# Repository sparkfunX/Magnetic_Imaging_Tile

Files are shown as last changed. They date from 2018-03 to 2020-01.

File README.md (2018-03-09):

Magnetic Imaging Tile
======

SparkFun Magnetic Imaging Tile

[*SparkFun Magnetic Imaging Tile (SPX-14652)*](https://www.sparkfun.com/products/14652)

The Magnetic Imaging Tile uses an array of 64 hall effect sensors to convert magnetic fields to the visual spectrum. That's right! You can now see magnetic fields in real time! As is to be expected, there are caveats: the magnetic sensors used on the tile are some of the most sensitive on the market but you need to be within 1 to 2 centimeters of the tile to get a good image.

This is a board intended to function as a "magnetic field camera" to visualize magnetic fields. 

This is an endorsed fork and collaboration of [Peter Jansen's work](https://hackaday.io/project/18518-iteration-8/log/91551-a-third-high-speed-magnetic-imager-tile). All credit goes to him! SparkX has re-designed the PCB for DFM and simiplified some of the platform interfacing code.

### Version 3.0

The major advancement of v3.0 is a dramatic increase in the speed with which the tile data can be read out. ~2000 frames per second (fps) can be achieved which allows visualizing even quickly varying fields (e.g. those in a 60Hz transformer, or a moving motor). Version 3.0 reduces the size of the tile to an 8x8 grid of hall effect sensors (64 total), arrayed in a 4mm grid.  The boards is tile-able with up to 4 of the boards tileable with minimal borders to create a 16x16 array. 

For more information (and a video of the v3.0 tile in use), please see: 
https://hackaday.io/project/18518-iteration-8/log/91551-a-third-high-speed-magnetic-imager-tile-draft

Repository Contents
-------------------

* **/Documents** - Datasheets for the RV-1805-C3 and super capacitor
* **/Hardware** - Eagle design files (.brd, .sch)

License Information
-------------------

This product is _**open source**_! 

Please review the LICENSE.md file for license information. 

If you have any questions or concerns on licensing, please contact techsupport@sparkfun.com.

Please use, reuse, and modify these files as you see fit. Please maintain attribution to SparkFun Electronics and release any derivative under the same license.

Disclaimer
-------------------

**DISCLAIMER OF WARRANTIES AND LIMITATION OF LIABILITY.**

UNLESS OTHERWISE SEPARATELY UNDERTAKEN BY THE LICENSOR, TO THE EXTENT POSSIBLE, THE LICENSOR OFFERS THE LICENSED MATERIAL AS-IS AND AS-AVAILABLE, AND MAKES NO REPRESENTATIONS OR WARRANTIES OF ANY KIND CONCERNING THE LICENSED MATERIAL, WHETHER EXPRESS, IMPLIED, STATUTORY, OR OTHER. THIS INCLUDES, WITHOUT LIMITATION, WARRANTIES OF TITLE, MERCHANTABILITY, FITNESS FOR A PARTICULAR PURPOSE, NON-INFRINGEMENT, ABSENCE OF LATENT OR OTHER DEFECTS, ACCURACY, OR THE PRESENCE OR ABSENCE OF ERRORS, WHETHER OR NOT KNOWN OR DISCOVERABLE. WHERE DISCLAIMERS OF WARRANTIES ARE NOT ALLOWED IN FULL OR IN PART, THIS DISCLAIMER MAY NOT APPLY TO YOU.

TO THE EXTENT POSSIBLE, IN NO EVENT WILL THE LICENSOR BE LIABLE TO YOU ON ANY LEGAL THEORY (INCLUDING, WITHOUT LIMITATION, NEGLIGENCE) OR OTHERWISE FOR ANY DIRECT, SPECIAL, INDIRECT, INCIDENTAL, CONSEQUENTIAL, PUNITIVE, EXEMPLARY, OR OTHER LOSSES, COSTS, EXPENSES, OR DAMAGES ARISING OUT OF THIS PUBLIC LICENSE OR USE OF THE LICENSED MATERIAL, EVEN IF THE LICENSOR HAS BEEN ADVISED OF THE POSSIBILITY OF SUCH LOSSES, COSTS, EXPENSES, OR DAMAGES. WHERE A LIMITATION OF LIABILITY IS NOT ALLOWED IN FULL OR IN PART, THIS LIMITATION MAY NOT APPLY TO YOU.

THE DISCLAIMER OF WARRANTIES AND LIMITATION OF LIABILITY PROVIDED ABOVE SHALL BE INTERPRETED IN A MANNER THAT, TO THE EXTENT POSSIBLE, MOST CLOSELY APPROXIMATES AN ABSOLUTE DISCLAIMER AND WAIVER OF ALL LIABILITY.

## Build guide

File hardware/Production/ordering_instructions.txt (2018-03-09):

panel size, 105x104mm
PCB thickness, 1.6mm
number of layers, 2
soldermask color, Black
silkscreen color, white
oz copper, 1oz
finish, HASL lead free
stencils, top+bottom

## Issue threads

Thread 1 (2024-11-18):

SCK and CLK labels are wrong on the mux side of the board

TurnerRussell50, 2024-11-18:
The hall-effect side is labeled correctly

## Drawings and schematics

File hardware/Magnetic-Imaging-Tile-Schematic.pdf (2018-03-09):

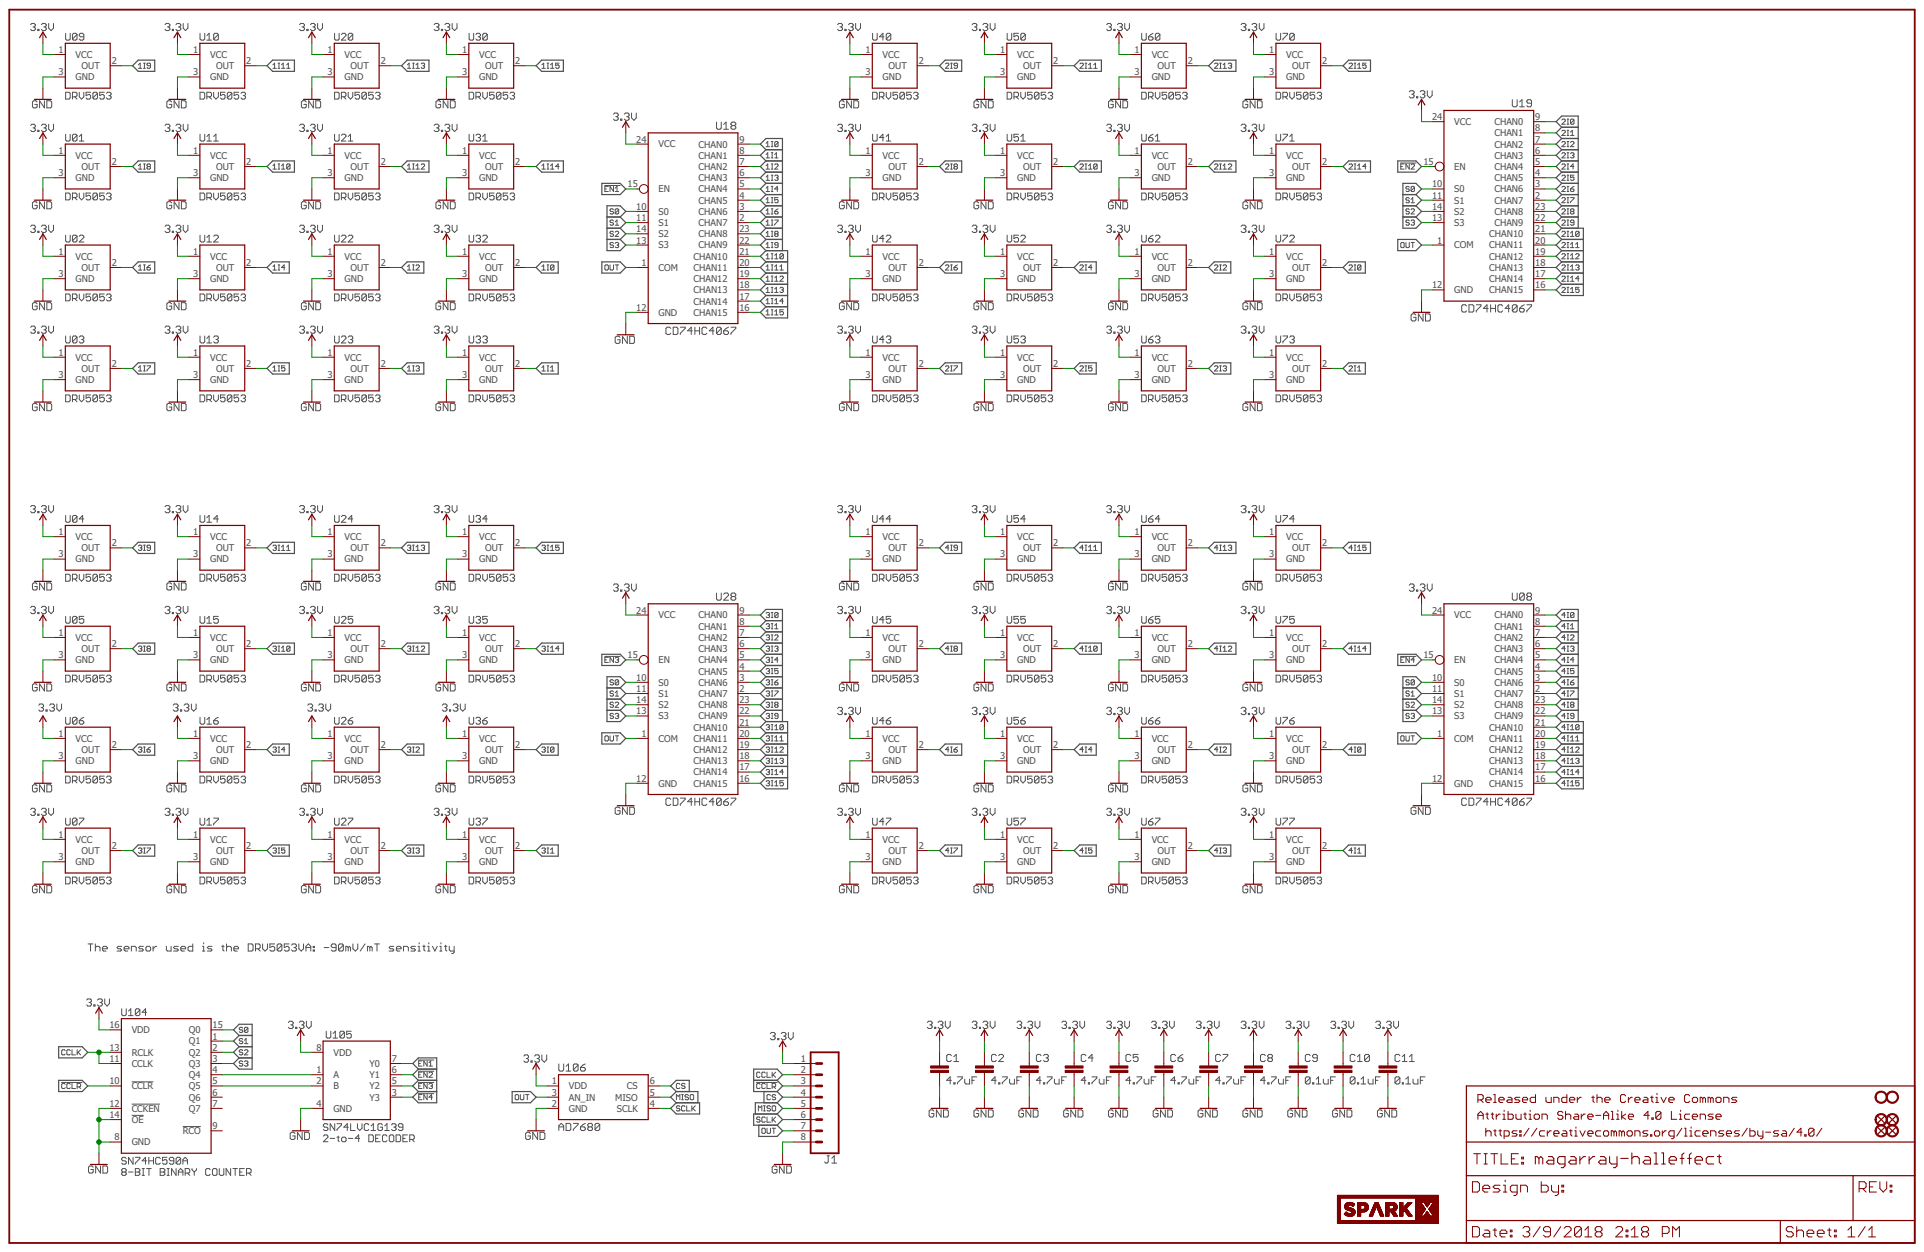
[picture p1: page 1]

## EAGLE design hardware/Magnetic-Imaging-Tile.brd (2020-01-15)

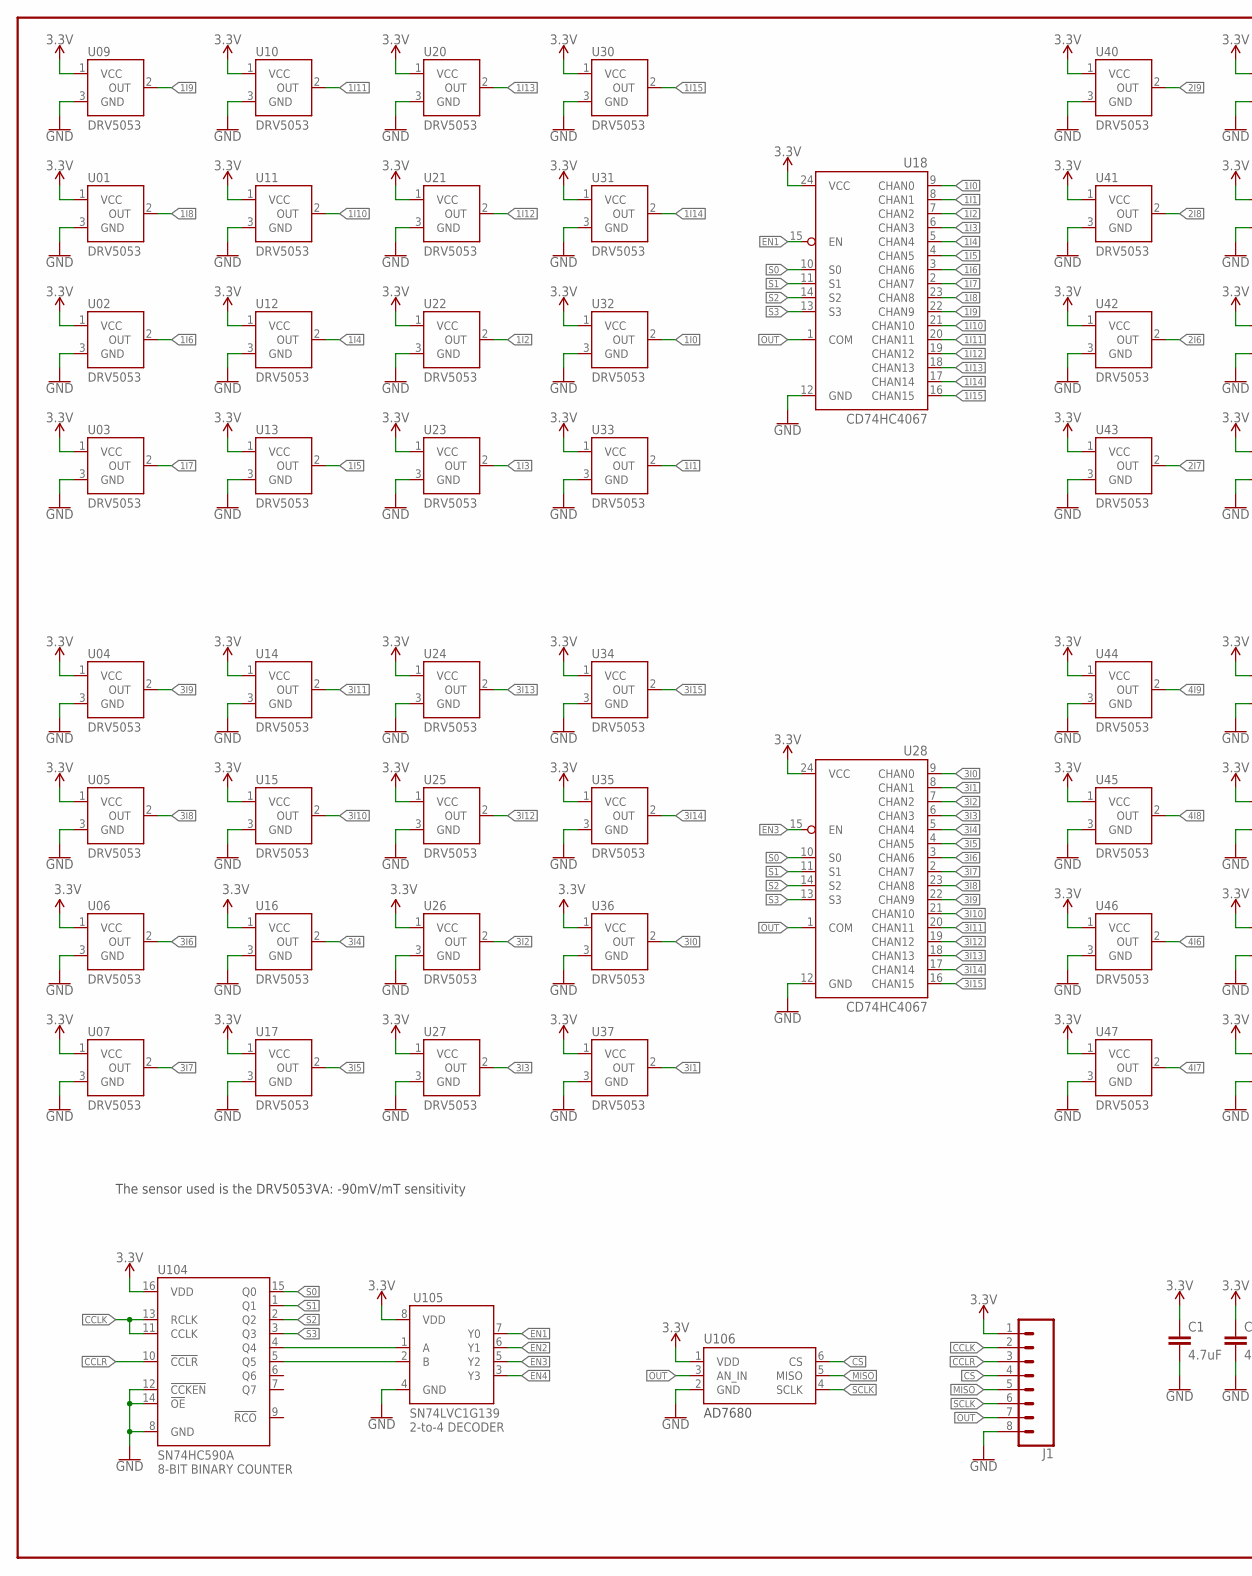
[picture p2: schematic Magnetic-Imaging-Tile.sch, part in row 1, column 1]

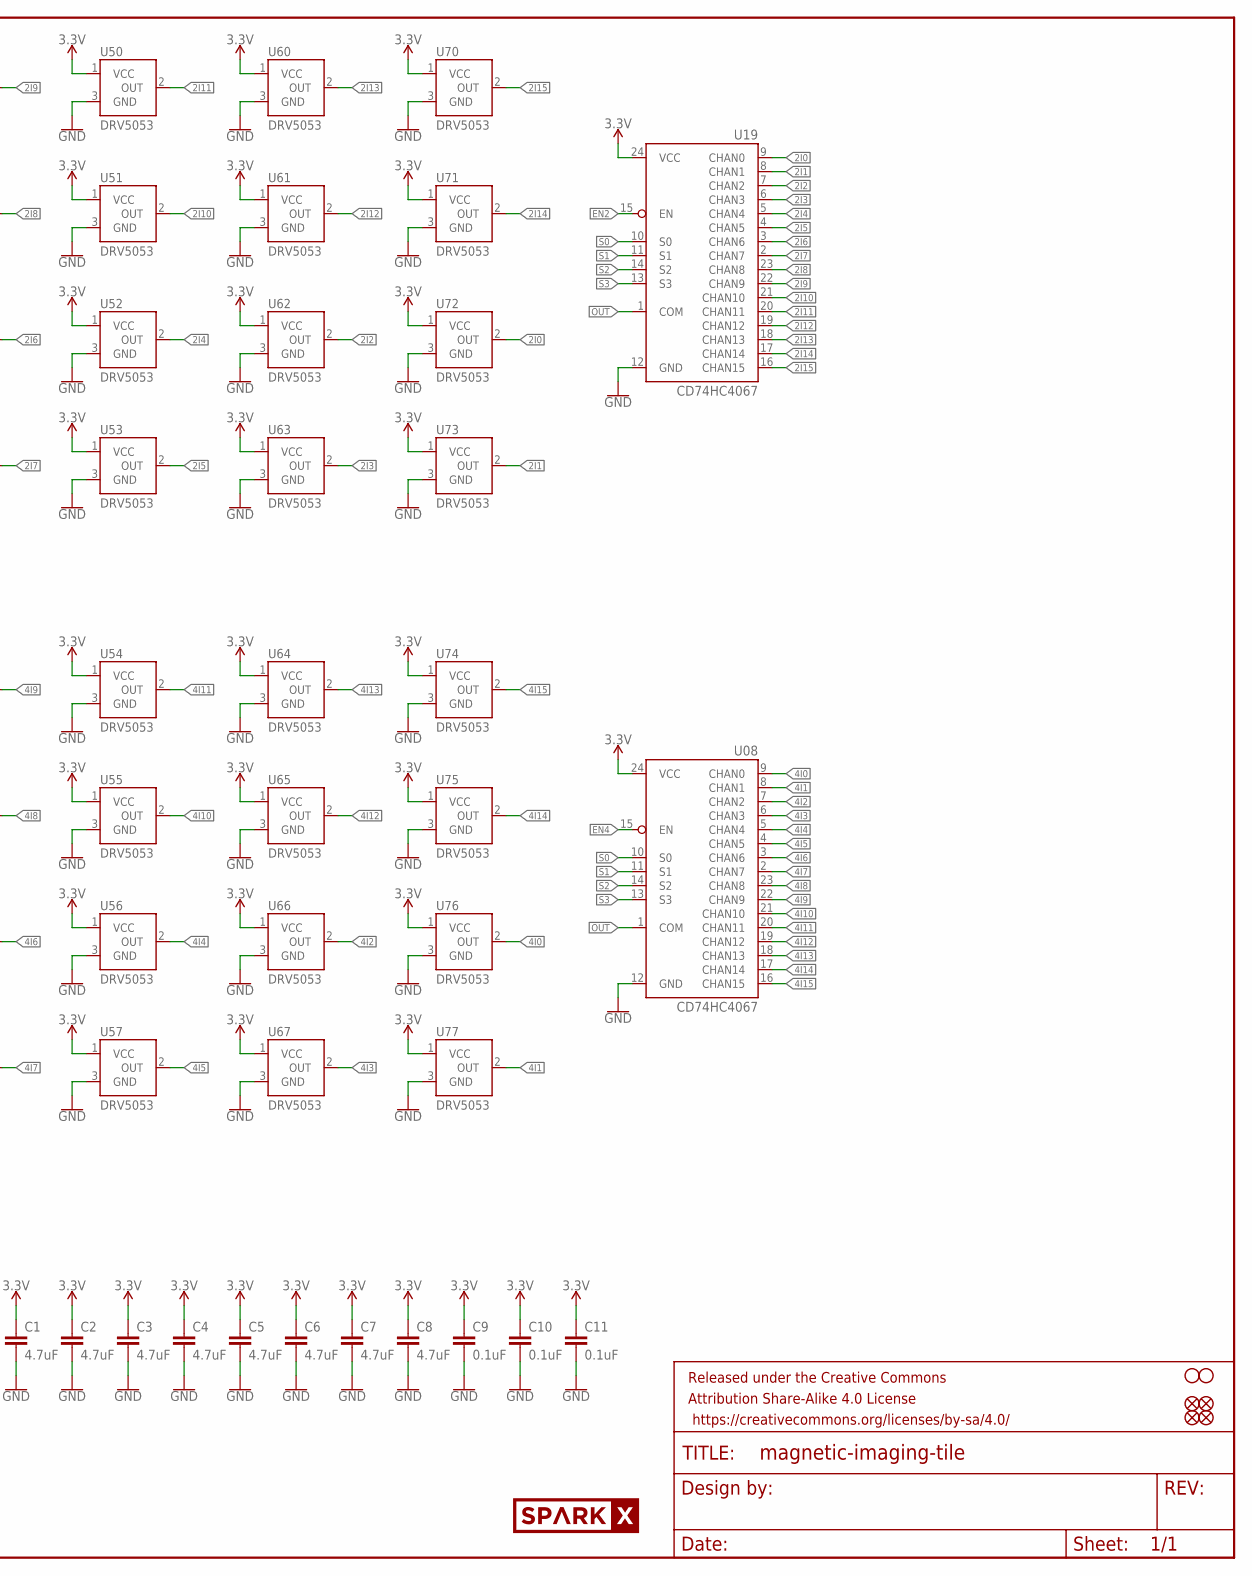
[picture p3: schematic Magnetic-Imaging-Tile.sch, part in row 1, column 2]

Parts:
C1, C2, C3, C4, C5, C6, C7, C8: 4.7uF; 0603
C9, C10, C11: 0.1uF; 0603
FD1, FD2, FD3, FD4: FIDUCIALUFIDUCIAL; FIDUCIAL-MICRO
FRAME1: FRAME-LEDGER; CREATIVE_COMMONS
H1, H2: STAND-OFF
J1: CONN_08LOCK_NO_SILK; 1X08_LOCK_NO_SILK
U01, U02, U03, U04, U05, U06, U07, U09, U10, U11, U12, U13, U14, U15, U16, U17, U20, U21, U22, U23, U24, U25, U26, U27, U30, U31, U32, U33, U34, U35, U36, U37, U40, U41, U42, U43, U44, U45, U46, U47, U50, U51, U52, U53, U54, U55, U56, U57, U60, U61, U62, U63, U64, U65, U66, U67, U70, U71, U72, U73, U74, U75, U76, U77: DRV5053; SOT23-3
U08, U18, U19, U28: CD74HC4067; SSOP24
U104: SN74HC590A; SO16
U105: SN74LVC1G139; SM8
U106: AD7680; SOT23-6
U$1: SPARKX-LOGO3; SPARKX-SMALL

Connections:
1I0: U18.9 (CHAN0), U32.2 (OUT)
1I1: U18.8 (CHAN1), U33.2 (OUT)
1I2: U18.7 (CHAN2), U22.2 (OUT)
1I3: U18.6 (CHAN3), U23.2 (OUT)
1I4: U12.2 (OUT), U18.5 (CHAN4)
1I5: U13.2 (OUT), U18.4 (CHAN5)
1I6: U02.2 (OUT), U18.3 (CHAN6)
1I7: U03.2 (OUT), U18.2 (CHAN7)
1I8: U01.2 (OUT), U18.23 (CHAN8)
1I9: U09.2 (OUT), U18.22 (CHAN9)
1I10: U11.2 (OUT), U18.21 (CHAN10)
1I11: U10.2 (OUT), U18.20 (CHAN11)
1I12: U18.19 (CHAN12), U21.2 (OUT)
1I13: U18.18 (CHAN13), U20.2 (OUT)
1I14: U18.17 (CHAN14), U31.2 (OUT)
1I15: U18.16 (CHAN15), U30.2 (OUT)
2I0: U19.9 (CHAN0), U72.2 (OUT)
2I1: U19.8 (CHAN1), U73.2 (OUT)
2I2: U19.7 (CHAN2), U62.2 (OUT)
2I3: U19.6 (CHAN3), U63.2 (OUT)
2I4: U19.5 (CHAN4), U52.2 (OUT)
2I5: U19.4 (CHAN5), U53.2 (OUT)
2I6: U19.3 (CHAN6), U42.2 (OUT)
2I7: U19.2 (CHAN7), U43.2 (OUT)
2I8: U19.23 (CHAN8), U41.2 (OUT)
2I9: U19.22 (CHAN9), U40.2 (OUT)
2I10: U19.21 (CHAN10), U51.2 (OUT)
2I11: U19.20 (CHAN11), U50.2 (OUT)
2I12: U19.19 (CHAN12), U61.2 (OUT)
2I13: U19.18 (CHAN13), U60.2 (OUT)
2I14: U19.17 (CHAN14), U71.2 (OUT)
2I15: U19.16 (CHAN15), U70.2 (OUT)
3.3V: C1.1, C2.1, C3.1, C4.1, C5.1, C6.1, C7.1, C8.1, C9.1, C10.1, C11.1, J1.1, U01.1 (VCC), U02.1 (VCC), U03.1 (VCC), U04.1 (VCC), U05.1 (VCC), U06.1 (VCC), U07.1 (VCC), U08.24 (VCC), U09.1 (VCC), U10.1 (VCC), U11.1 (VCC), U12.1 (VCC), U13.1 (VCC), U14.1 (VCC), U15.1 (VCC), U16.1 (VCC), U17.1 (VCC), U18.24 (VCC), U19.24 (VCC), U20.1 (VCC), U21.1 (VCC), U22.1 (VCC), U23.1 (VCC), U24.1 (VCC), U25.1 (VCC), U26.1 (VCC), U27.1 (VCC), U28.24 (VCC), U30.1 (VCC), U31.1 (VCC), U32.1 (VCC), U33.1 (VCC), U34.1 (VCC), U35.1 (VCC), U36.1 (VCC), U37.1 (VCC), U40.1 (VCC), U41.1 (VCC), U42.1 (VCC), U43.1 (VCC), U44.1 (VCC), U45.1 (VCC), U46.1 (VCC), U47.1 (VCC), U50.1 (VCC), U51.1 (VCC), U52.1 (VCC), U53.1 (VCC), U54.1 (VCC), U55.1 (VCC), U56.1 (VCC), U57.1 (VCC), U60.1 (VCC), U61.1 (VCC), U62.1 (VCC), U63.1 (VCC), U64.1 (VCC), U65.1 (VCC), U66.1 (VCC), U67.1 (VCC), U70.1 (VCC), U71.1 (VCC), U72.1 (VCC), U73.1 (VCC), U74.1 (VCC), U75.1 (VCC), U76.1 (VCC), U77.1 (VCC), U104.16 (VDD), U105.8 (VDD), U106.1 (VDD)
3I0: U28.9 (CHAN0), U36.2 (OUT)
3I1: U28.8 (CHAN1), U37.2 (OUT)
3I2: U26.2 (OUT), U28.7 (CHAN2)
3I3: U27.2 (OUT), U28.6 (CHAN3)
3I4: U16.2 (OUT), U28.5 (CHAN4)
3I5: U17.2 (OUT), U28.4 (CHAN5)
3I6: U06.2 (OUT), U28.3 (CHAN6)
3I7: U07.2 (OUT), U28.2 (CHAN7)
3I8: U05.2 (OUT), U28.23 (CHAN8)
3I9: U04.2 (OUT), U28.22 (CHAN9)
3I10: U15.2 (OUT), U28.21 (CHAN10)
3I11: U14.2 (OUT), U28.20 (CHAN11)
3I12: U25.2 (OUT), U28.19 (CHAN12)
3I13: U24.2 (OUT), U28.18 (CHAN13)
3I14: U28.17 (CHAN14), U35.2 (OUT)
3I15: U28.16 (CHAN15), U34.2 (OUT)
4I0: U08.9 (CHAN0), U76.2 (OUT)
4I1: U08.8 (CHAN1), U77.2 (OUT)
4I2: U08.7 (CHAN2), U66.2 (OUT)
4I3: U08.6 (CHAN3), U67.2 (OUT)
4I4: U08.5 (CHAN4), U56.2 (OUT)
4I5: U08.4 (CHAN5), U57.2 (OUT)
4I6: U08.3 (CHAN6), U46.2 (OUT)
4I7: U08.2 (CHAN7), U47.2 (OUT)
4I8: U08.23 (CHAN8), U45.2 (OUT)
4I9: U08.22 (CHAN9), U44.2 (OUT)
4I10: U08.21 (CHAN10), U55.2 (OUT)
4I11: U08.20 (CHAN11), U54.2 (OUT)
4I12: U08.19 (CHAN12), U65.2 (OUT)
4I13: U08.18 (CHAN13), U64.2 (OUT)
4I14: U08.17 (CHAN14), U75.2 (OUT)
4I15: U08.16 (CHAN15), U74.2 (OUT)
!CCLR: J1.3, U104.10 (!CCLR)
!EN1: U18.15 (EN), U105.7 (Y0)
!EN2: U19.15 (EN), U105.6 (Y1)
!EN3: U28.15 (EN), U105.5 (Y2)
!EN4: U08.15 (EN), U105.3 (Y3)
CCLK: J1.2, U104.11 (CCLK), U104.13 (RCLK)
CS: J1.4, U106.6 (CS)
GND: C1.2, C2.2, C3.2, C4.2, C5.2, C6.2, C7.2, C8.2, C9.2, C10.2, C11.2, J1.8, U01.3 (GND), U02.3 (GND), U03.3 (GND), U04.3 (GND), U05.3 (GND), U06.3 (GND), U07.3 (GND), U08.12 (GND), U09.3 (GND), U10.3 (GND), U11.3 (GND), U12.3 (GND), U13.3 (GND), U14.3 (GND), U15.3 (GND), U16.3 (GND), U17.3 (GND), U18.12 (GND), U19.12 (GND), U20.3 (GND), U21.3 (GND), U22.3 (GND), U23.3 (GND), U24.3 (GND), U25.3 (GND), U26.3 (GND), U27.3 (GND), U28.12 (GND), U30.3 (GND), U31.3 (GND), U32.3 (GND), U33.3 (GND), U34.3 (GND), U35.3 (GND), U36.3 (GND), U37.3 (GND), U40.3 (GND), U41.3 (GND), U42.3 (GND), U43.3 (GND), U44.3 (GND), U45.3 (GND), U46.3 (GND), U47.3 (GND), U50.3 (GND), U51.3 (GND), U52.3 (GND), U53.3 (GND), U54.3 (GND), U55.3 (GND), U56.3 (GND), U57.3 (GND), U60.3 (GND), U61.3 (GND), U62.3 (GND), U63.3 (GND), U64.3 (GND), U65.3 (GND), U66.3 (GND), U67.3 (GND), U70.3 (GND), U71.3 (GND), U72.3 (GND), U73.3 (GND), U74.3 (GND), U75.3 (GND), U76.3 (GND), U77.3 (GND), U104.8 (GND), U104.12 (!CCKEN), U104.14 (!OE), U105.4 (GND), U106.2 (GND)
MISO: J1.5, U106.5 (MISO)
unnamed: U104.4 (Q4), U105.1 (A)
unnamed: U104.5 (Q5), U105.2 (B)
OUT: J1.7, U08.1 (COM), U18.1 (COM), U19.1 (COM), U28.1 (COM), U106.3 (AN_IN)
S0: U08.10 (S0), U18.10 (S0), U19.10 (S0), U28.10 (S0), U104.15 (Q0)
S1: U08.11 (S1), U18.11 (S1), U19.11 (S1), U28.11 (S1), U104.1 (Q1)
S2: U08.14 (S2), U18.14 (S2), U19.14 (S2), U28.14 (S2), U104.2 (Q2)
S3: U08.13 (S3), U18.13 (S3), U19.13 (S3), U28.13 (S3), U104.3 (Q3)
SCLK: J1.6, U106.4 (SCLK)

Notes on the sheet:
The sensor used is the DRV5053VA: -90mV/mT sensitivity

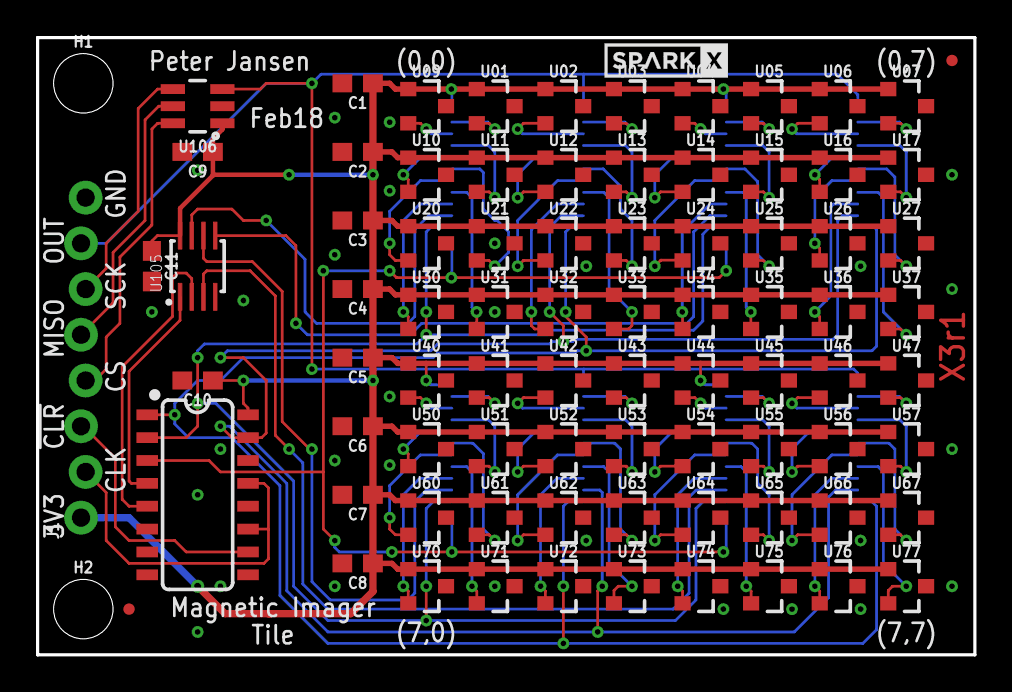
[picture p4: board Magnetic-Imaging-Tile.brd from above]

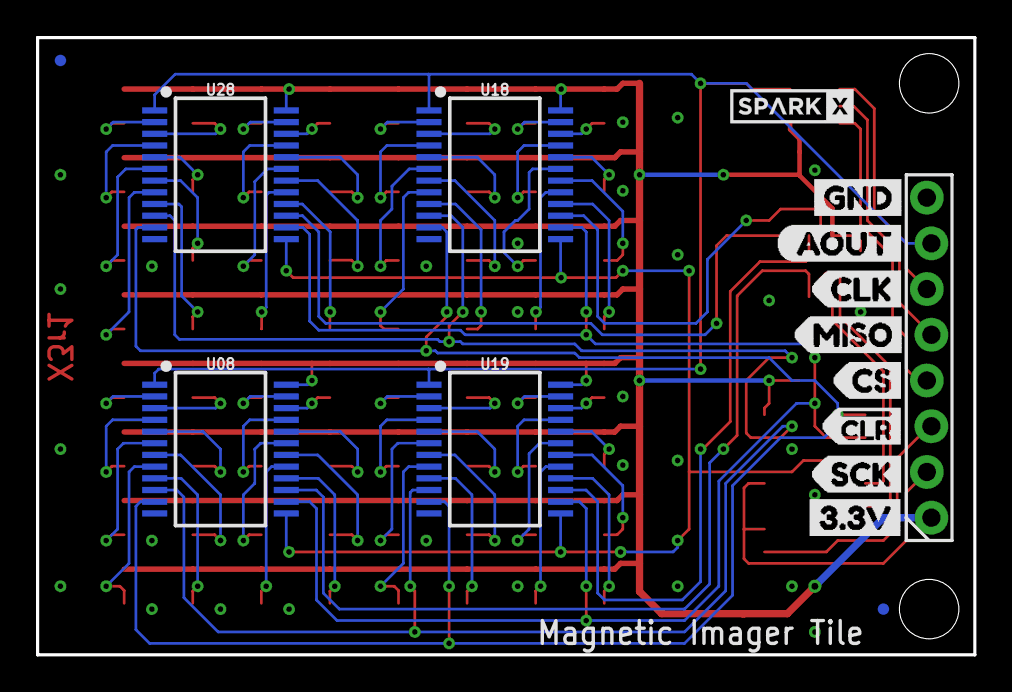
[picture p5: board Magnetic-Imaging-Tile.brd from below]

Board: 2 copper layers, 52.1 x 34.3 mm, 100 parts (15 on the bottom side), 82 nets.

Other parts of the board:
U$2: SPARKX-LOGO3; SPARKX-SMALL
U$3: GND
U$4: #CLR
U$5: 3#3V
U$6: AOUT
U$7: CLK
U$8: MISO
U$9: SCK
U$10: CS

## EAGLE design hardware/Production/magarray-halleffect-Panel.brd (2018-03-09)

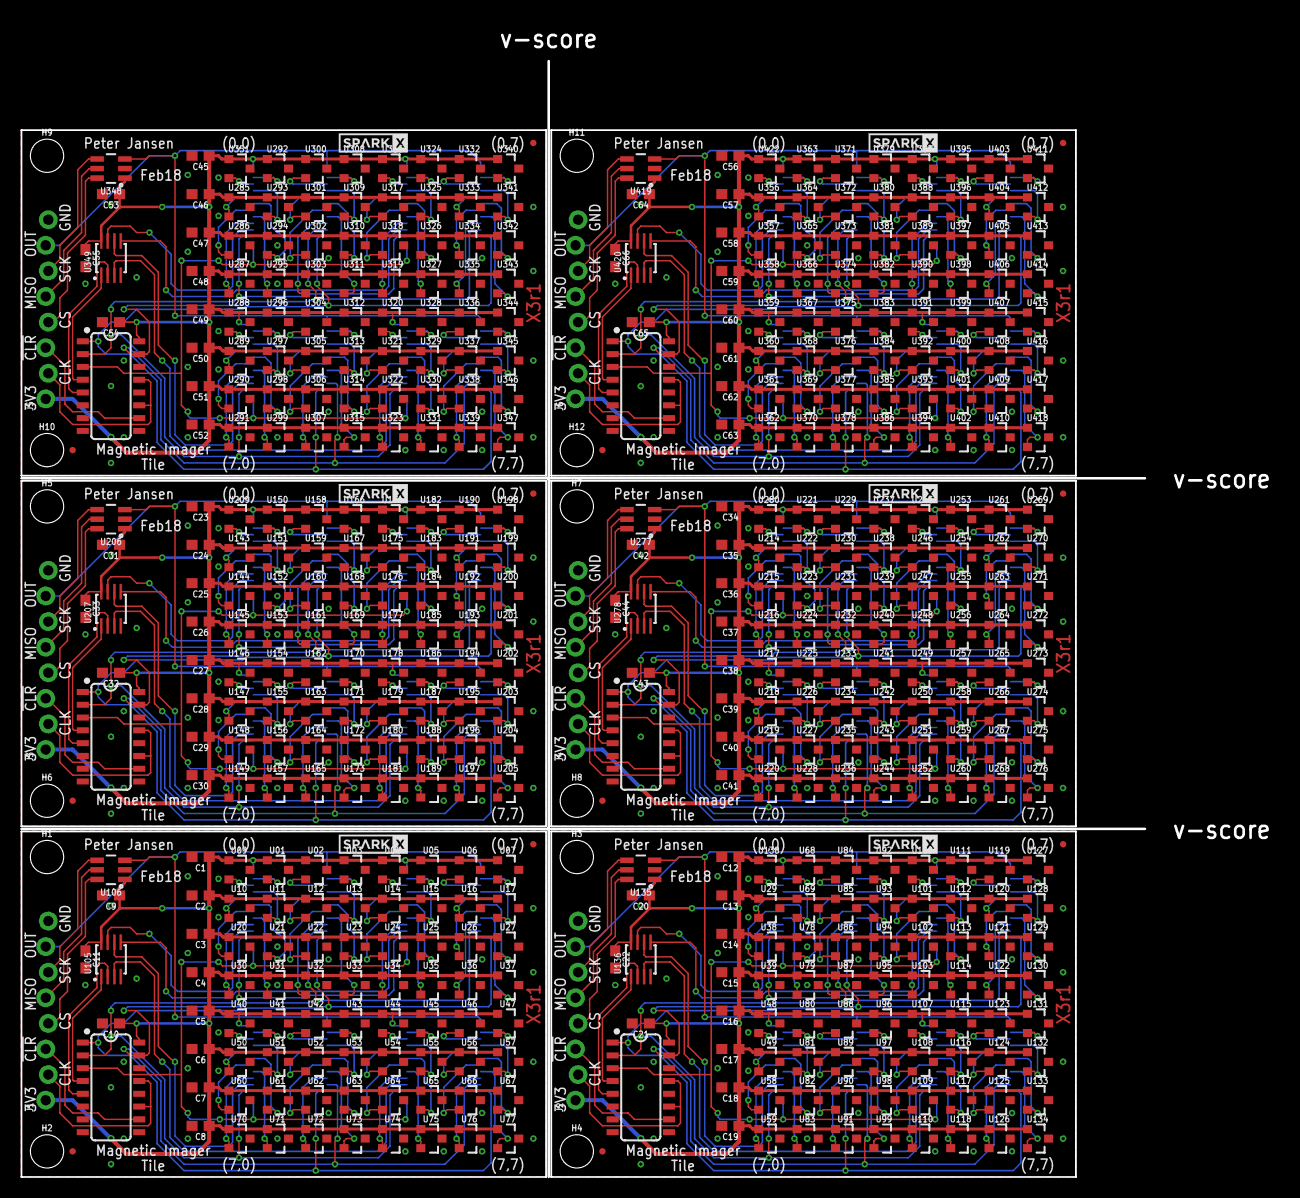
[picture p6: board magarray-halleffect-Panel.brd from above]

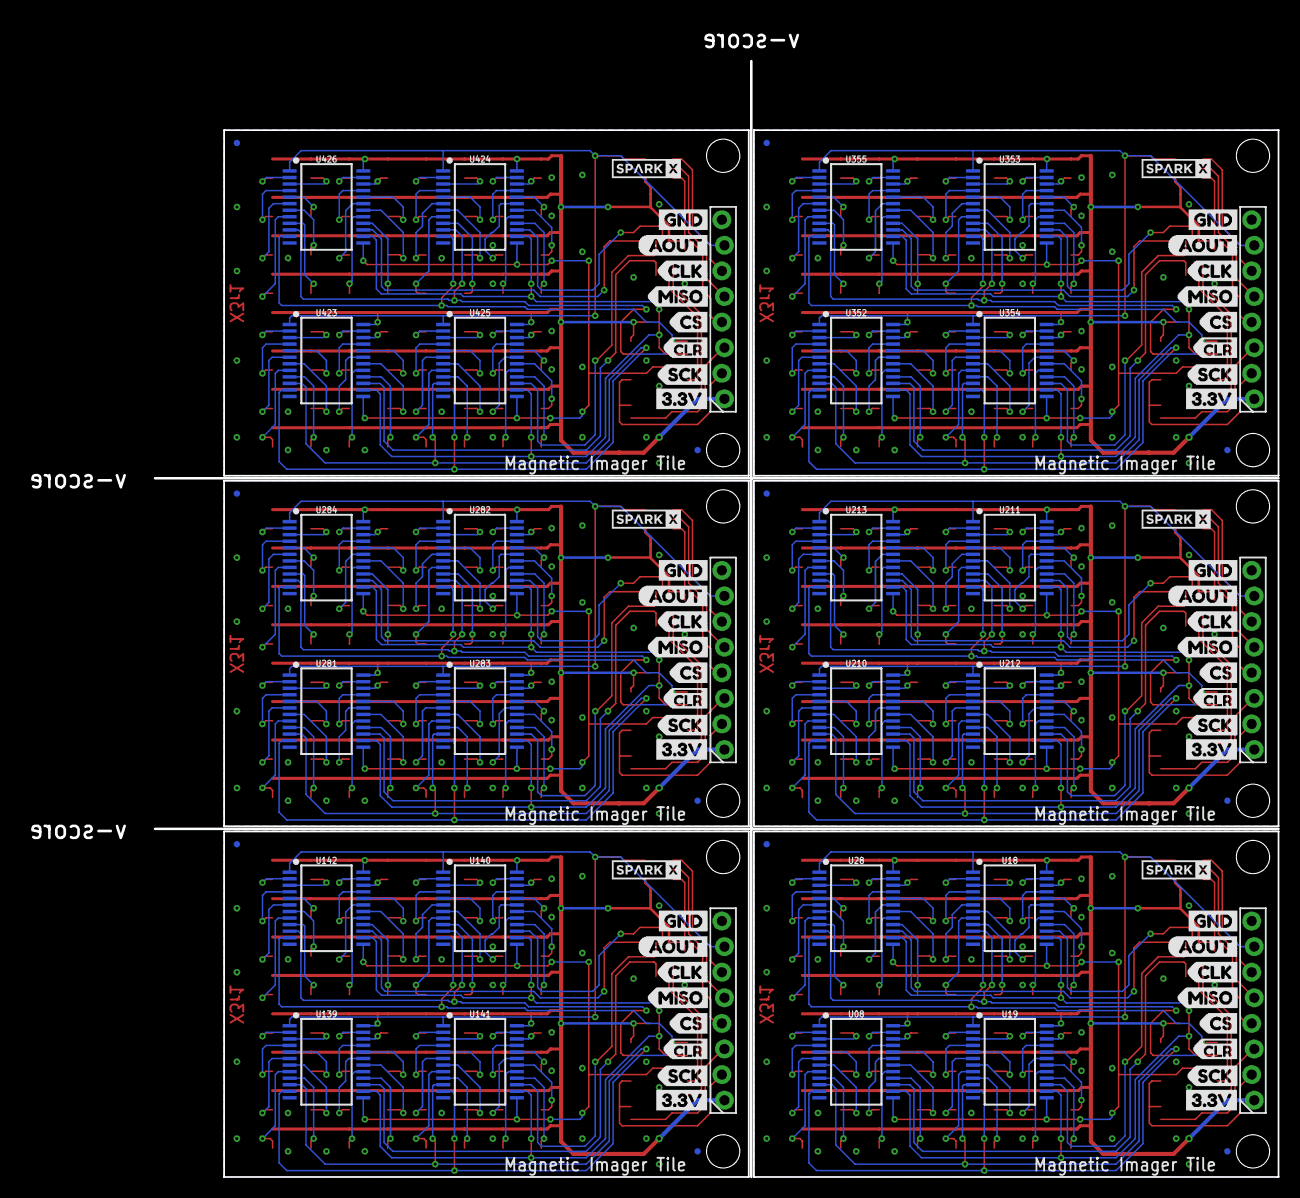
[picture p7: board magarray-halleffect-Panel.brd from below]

Board: 2 copper layers, 111.5 x 110.7 mm, 594 parts (90 on the bottom side), 492 nets.

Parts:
C1, C2, C3, C4, C5, C6, C7, C8, C12, C13, C14, C15, C16, C17, C18, C19, C23, C24, C25, C26, C27, C28, C29, C30, C34, C35, C36, C37, C38, C39, C40, C41, C45, C46, C47, C48, C49, C50, C51, C52, C56, C57, C58, C59, C60, C61, C62, C63: 4.7uF; 0603
C9, C10, C11, C20, C21, C22, C31, C32, C33, C42, C43, C44, C53, C54, C55, C64, C65, C66: 0.1uF; 0603
FD1, FD2, FD3, FD4, FD5, FD6, FD7, FD8, FD9, FD10, FD11, FD12, FD13, FD14, FD15, FD16, FD17, FD18, FD19, FD20, FD21, FD22, FD23, FD24: FIDUCIALUFIDUCIAL; FIDUCIAL-MICRO
H1, H2, H3, H4, H5, H6, H7, H8, H9, H10, H11, H12: STAND-OFF
J1, J2, J3, J4, J5, J6: 1X08_LOCK_NO_SILK
U01, U02, U03, U04, U05, U06, U07, U09, U10, U11, U12, U13, U14, U15, U16, U17, U20, U21, U22, U23, U24, U25, U26, U27, U29, U30, U31, U32, U33, U34, U35, U36, U37, U38, U39, U40, U41, U42, U43, U44, U45, U46, U47, U48, U49, U50, U51, U52, U53, U54, U55, U56, U57, U58, U59, U60, U61, U62, U63, U64, U65, U66, U67, U68, U69, U70, U71, U72, U73, U74, U75, U76, U77, U78, U79, U80, U81, U82, U83, U84, U85, U86, U87, U88, U89, U90, U91, U92, U93, U94, U95, U96, U97, U98, U99, U100, U101, U102, U103, U107, U108, U109, U110, U111, U112, U113, U114, U115, U116, U117, U118, U119, U120, U121, U122, U123, U124, U125, U126, U127, U128, U129, U130, U131, U132, U133, U134, U138, U143, U144, U145, U146, U147, U148, U149, U150, U151, U152, U153, U154, U155, U156, U157, U158, U159, U160, U161, U162, U163, U164, U165, U166, U167, U168, U169, U170, U171, U172, U173, U174, U175, U176, U177, U178, U179, U180, U181, U182, U183, U184, U185, U186, U187, U188, U189, U190, U191, U192, U193, U194, U195, U196, U197, U198, U199, U200, U201, U202, U203, U204, U205, U209, U214, U215, U216, U217, U218, U219, U220, U221, U222, U223, U224, U225, U226, U227, U228, U229, U230, U231, U232, U233, U234, U235, U236, U237, U238, U239, U240, U241, U242, U243, U244, U245, U246, U247, U248, U249, U250, U251, U252, U253, U254, U255, U256, U257, U258, U259, U260, U261, U262, U263, U264, U265, U266, U267, U268, U269, U270, U271, U272, U273, U274, U275, U276, U280, U285, U286, U287, U288, U289, U290, U291, U292, U293, U294, U295, U296, U297, U298, U299, U300, U301, U302, U303, U304, U305, U306, U307, U308, U309, U310, U311, U312, U313, U314, U315, U316, U317, U318, U319, U320, U321, U322, U323, U324, U325, U326, U327, U328, U329, U330, U331, U332, U333, U334, U335, U336, U337, U338, U339, U340, U341, U342, U343, U344, U345, U346, U347, U351, U356, U357, U358, U359, U360, U361, U362, U363, U364, U365, U366, U367, U368, U369, U370, U371, U372, U373, U374, U375, U376, U377, U378, U379, U380, U381, U382, U383, U384, U385, U386, U387, U388, U389, U390, U391, U392, U393, U394, U395, U396, U397, U398, U399, U400, U401, U402, U403, U404, U405, U406, U407, U408, U409, U410, U411, U412, U413, U414, U415, U416, U417, U418, U422: DRV5053; SOT23-3
U08, U18, U19, U28, U139, U140, U141, U142, U210, U211, U212, U213, U281, U282, U283, U284, U352, U353, U354, U355, U423, U424, U425, U426: CD74HC4067; SSOP24
U104, U137, U208, U279, U350, U421: SN74HC509A; SO16
U105, U136, U207, U278, U349, U420: SN74LVC1G139; SM8
U106, U135, U206, U277, U348, U419: AD7940; SOT23-6
U$1, U$2, U$11, U$12, U$21, U$22, U$31, U$32, U$41, U$42, U$51, U$52: SPARKX-LOGO3; SPARKX-SMALL
U$3, U$13, U$23, U$33, U$43, U$53: GND
U$4, U$19, U$29, U$39, U$49, U$59: #CLR
U$5, U$14, U$24, U$34, U$44, U$54: 3#3V
U$6, U$15, U$25, U$35, U$45, U$55: AOUT
U$7, U$16, U$26, U$36, U$46, U$56: CLK
U$8, U$17, U$27, U$37, U$47, U$57: MISO
U$9, U$18, U$28, U$38, U$48, U$58: SCK
U$10, U$20, U$30, U$40, U$50, U$60: CS

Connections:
1I0: U18.9, U32.2
1I1: U18.8, U33.2
1I2: U18.7, U22.2
1I3: U18.6, U23.2
1I4: U12.2, U18.5
1I5: U13.2, U18.4
1I6: U02.2, U18.3
1I7: U03.2, U18.2
1I8: U01.2, U18.23
1I9: U09.2, U18.22
1I10: U11.2, U18.21
1I11: U10.2, U18.20
1I12: U18.19, U21.2
1I13: U18.18, U20.2
1I14: U18.17, U31.2
1I15: U18.16, U30.2
1I16: U87.2, U140.9
1I17: U95.2, U140.8
1I18: U86.2, U140.7
1I19: U94.2, U140.6
1I20: U85.2, U140.5
1I21: U93.2, U140.4
1I22: U84.2, U140.3
1I23: U92.2, U140.2
1I24: U68.2, U140.23
1I25: U138.2, U140.22
1I26: U69.2, U140.21
1I27: U29.2, U140.20
1I28: U78.2, U140.19
1I29: U38.2, U140.18
1I30: U79.2, U140.17
1I31: U39.2, U140.16
1I32: U161.2, U211.9
1I33: U169.2, U211.8
1I34: U160.2, U211.7
1I35: U168.2, U211.6
1I36: U159.2, U211.5
1I37: U167.2, U211.4
1I38: U158.2, U211.3
1I39: U166.2, U211.2
1I40: U150.2, U211.23
1I41: U209.2, U211.22
1I42: U151.2, U211.21
1I43: U143.2, U211.20
1I44: U152.2, U211.19
1I45: U144.2, U211.18
1I46: U153.2, U211.17
1I47: U145.2, U211.16
1I48: U232.2, U282.9
1I49: U240.2, U282.8
1I50: U231.2, U282.7
1I51: U239.2, U282.6
1I52: U230.2, U282.5
1I53: U238.2, U282.4
1I54: U229.2, U282.3
1I55: U237.2, U282.2
1I56: U221.2, U282.23
1I57: U280.2, U282.22
1I58: U222.2, U282.21
1I59: U214.2, U282.20
1I60: U223.2, U282.19
1I61: U215.2, U282.18
1I62: U224.2, U282.17
1I63: U216.2, U282.16
1I64: U303.2, U353.9
1I65: U311.2, U353.8
1I66: U302.2, U353.7
1I67: U310.2, U353.6
1I68: U301.2, U353.5
1I69: U309.2, U353.4
1I70: U300.2, U353.3
1I71: U308.2, U353.2
1I72: U292.2, U353.23
1I73: U351.2, U353.22
1I74: U293.2, U353.21
1I75: U285.2, U353.20
1I76: U294.2, U353.19
1I77: U286.2, U353.18
1I78: U295.2, U353.17
1I79: U287.2, U353.16
1I80: U374.2, U424.9
1I81: U382.2, U424.8
1I82: U373.2, U424.7
1I83: U381.2, U424.6
1I84: U372.2, U424.5
1I85: U380.2, U424.4
1I86: U371.2, U424.3
1I87: U379.2, U424.2
1I88: U363.2, U424.23
1I89: U422.2, U424.22
1I90: U364.2, U424.21
1I91: U356.2, U424.20
1I92: U365.2, U424.19
1I93: U357.2, U424.18
1I94: U366.2, U424.17
1I95: U358.2, U424.16
2I0: U19.9, U72.2
2I1: U19.8, U73.2
2I2: U19.7, U62.2
2I3: U19.6, U63.2
2I4: U19.5, U52.2
2I5: U19.4, U53.2
2I6: U19.3, U42.2
2I7: U19.2, U43.2
2I8: U19.23, U41.2
2I9: U19.22, U40.2
2I10: U19.21, U51.2
2I11: U19.20, U50.2
2I12: U19.19, U61.2
2I13: U19.18, U60.2
2I14: U19.17, U71.2
2I15: U19.16, U70.2
2I16: U91.2, U141.9
2I17: U99.2, U141.8
2I18: U90.2, U141.7
2I19: U98.2, U141.6
2I20: U89.2, U141.5
2I21: U97.2, U141.4
2I22: U88.2, U141.3
2I23: U96.2, U141.2
2I24: U80.2, U141.23
2I25: U48.2, U141.22
2I26: U81.2, U141.21
2I27: U49.2, U141.20
2I28: U82.2, U141.19
2I29: U58.2, U141.18
2I30: U83.2, U141.17
2I31: U59.2, U141.16
2I32: U165.2, U212.9
2I33: U173.2, U212.8
2I34: U164.2, U212.7
2I35: U172.2, U212.6
2I36: U163.2, U212.5
2I37: U171.2, U212.4
2I38: U162.2, U212.3
2I39: U170.2, U212.2
2I40: U154.2, U212.23
2I41: U146.2, U212.22
2I42: U155.2, U212.21
2I43: U147.2, U212.20
2I44: U156.2, U212.19
2I45: U148.2, U212.18
2I46: U157.2, U212.17
2I47: U149.2, U212.16
2I48: U236.2, U283.9
2I49: U244.2, U283.8
2I50: U235.2, U283.7
2I51: U243.2, U283.6
2I52: U234.2, U283.5
2I53: U242.2, U283.4
2I54: U233.2, U283.3
2I55: U241.2, U283.2
2I56: U225.2, U283.23
2I57: U217.2, U283.22
2I58: U226.2, U283.21
2I59: U218.2, U283.20
2I60: U227.2, U283.19
2I61: U219.2, U283.18
2I62: U228.2, U283.17
2I63: U220.2, U283.16
2I64: U307.2, U354.9
2I65: U315.2, U354.8
2I66: U306.2, U354.7
2I67: U314.2, U354.6
2I68: U305.2, U354.5
2I69: U313.2, U354.4
2I70: U304.2, U354.3
2I71: U312.2, U354.2
2I72: U296.2, U354.23
2I73: U288.2, U354.22
2I74: U297.2, U354.21
2I75: U289.2, U354.20
2I76: U298.2, U354.19
2I77: U290.2, U354.18
2I78: U299.2, U354.17
2I79: U291.2, U354.16
2I80: U378.2, U425.9
2I81: U386.2, U425.8
2I82: U377.2, U425.7
2I83: U385.2, U425.6
2I84: U376.2, U425.5
2I85: U384.2, U425.4
2I86: U375.2, U425.3
2I87: U383.2, U425.2
2I88: U367.2, U425.23
2I89: U359.2, U425.22
2I90: U368.2, U425.21
2I91: U360.2, U425.20
2I92: U369.2, U425.19
2I93: U361.2, U425.18
2I94: U370.2, U425.17
2I95: U362.2, U425.16
3.3V: C1.1, C2.1, C3.1, C4.1, C5.1, C6.1, C7.1, C8.1, C9.1, C10.1, C11.1, J1.1, U01.1, U02.1, U03.1, U04.1, U05.1, U06.1, U07.1, U08.24, U09.1, U10.1, U11.1, U12.1, U13.1, U14.1, U15.1, U16.1, U17.1, U18.24, U19.24, U20.1, U21.1, U22.1, U23.1, U24.1, U25.1, U26.1, U27.1, U28.24, U30.1, U31.1, U32.1, U33.1, U34.1, U35.1, U36.1, U37.1, U40.1, U41.1, U42.1, U43.1, U44.1, U45.1, U46.1, U47.1, U50.1, U51.1, U52.1, U53.1, U54.1, U55.1, U56.1, U57.1, U60.1, U61.1, U62.1, U63.1, U64.1, U65.1, U66.1, U67.1, U70.1, U71.1, U72.1, U73.1, U74.1, U75.1, U76.1, U77.1, U104.16, U105.8, U106.1
3.3V1: C12.1, C13.1, C14.1, C15.1, C16.1, C17.1, C18.1, C19.1, C20.1, C21.1, C22.1, J2.1, U29.1, U38.1, U39.1, U48.1, U49.1, U58.1, U59.1, U68.1, U69.1, U78.1, U79.1, U80.1, U81.1, U82.1, U83.1, U84.1, U85.1, U86.1, U87.1, U88.1, U89.1, U90.1, U91.1, U92.1, U93.1, U94.1, U95.1, U96.1, U97.1, U98.1, U99.1, U100.1, U101.1, U102.1, U103.1, U107.1, U108.1, U109.1, U110.1, U111.1, U112.1, U113.1, U114.1, U115.1, U116.1, U117.1, U118.1, U119.1, U120.1, U121.1, U122.1, U123.1, U124.1, U125.1, U126.1, U127.1, U128.1, U129.1, U130.1, U131.1, U132.1, U133.1, U134.1, U135.1, U136.8, U137.16, U138.1, U139.24, U140.24, U141.24, U142.24
3.3V2: C23.1, C24.1, C25.1, C26.1, C27.1, C28.1, C29.1, C30.1, C31.1, C32.1, C33.1, J3.1, U143.1, U144.1, U145.1, U146.1, U147.1, U148.1, U149.1, U150.1, U151.1, U152.1, U153.1, U154.1, U155.1, U156.1, U157.1, U158.1, U159.1, U160.1, U161.1, U162.1, U163.1, U164.1, U165.1, U166.1, U167.1, U168.1, U169.1, U170.1, U171.1, U172.1, U173.1, U174.1, U175.1, U176.1, U177.1, U178.1, U179.1, U180.1, U181.1, U182.1, U183.1, U184.1, U185.1, U186.1, U187.1, U188.1, U189.1, U190.1, U191.1, U192.1, U193.1, U194.1, U195.1, U196.1, U197.1, U198.1, U199.1, U200.1, U201.1, U202.1, U203.1, U204.1, U205.1, U206.1, U207.8, U208.16, U209.1, U210.24, U211.24, U212.24, U213.24
3.3V3: C34.1, C35.1, C36.1, C37.1, C38.1, C39.1, C40.1, C41.1, C42.1, C43.1, C44.1, J4.1, U214.1, U215.1, U216.1, U217.1, U218.1, U219.1, U220.1, U221.1, U222.1, U223.1, U224.1, U225.1, U226.1, U227.1, U228.1, U229.1, U230.1, U231.1, U232.1, U233.1, U234.1, U235.1, U236.1, U237.1, U238.1, U239.1, U240.1, U241.1, U242.1, U243.1, U244.1, U245.1, U246.1, U247.1, U248.1, U249.1, U250.1, U251.1, U252.1, U253.1, U254.1, U255.1, U256.1, U257.1, U258.1, U259.1, U260.1, U261.1, U262.1, U263.1, U264.1, U265.1, U266.1, U267.1, U268.1, U269.1, U270.1, U271.1, U272.1, U273.1, U274.1, U275.1, U276.1, U277.1, U278.8, U279.16, U280.1, U281.24, U282.24, U283.24, U284.24
3.3V4: C45.1, C46.1, C47.1, C48.1, C49.1, C50.1, C51.1, C52.1, C53.1, C54.1, C55.1, J5.1, U285.1, U286.1, U287.1, U288.1, U289.1, U290.1, U291.1, U292.1, U293.1, U294.1, U295.1, U296.1, U297.1, U298.1, U299.1, U300.1, U301.1, U302.1, U303.1, U304.1, U305.1, U306.1, U307.1, U308.1, U309.1, U310.1, U311.1, U312.1, U313.1, U314.1, U315.1, U316.1, U317.1, U318.1, U319.1, U320.1, U321.1, U322.1, U323.1, U324.1, U325.1, U326.1, U327.1, U328.1, U329.1, U330.1, U331.1, U332.1, U333.1, U334.1, U335.1, U336.1, U337.1, U338.1, U339.1, U340.1, U341.1, U342.1, U343.1, U344.1, U345.1, U346.1, U347.1, U348.1, U349.8, U350.16, U351.1, U352.24, U353.24, U354.24, U355.24
3.3V5: C56.1, C57.1, C58.1, C59.1, C60.1, C61.1, C62.1, C63.1, C64.1, C65.1, C66.1, J6.1, U356.1, U357.1, U358.1, U359.1, U360.1, U361.1, U362.1, U363.1, U364.1, U365.1, U366.1, U367.1, U368.1, U369.1, U370.1, U371.1, U372.1, U373.1, U374.1, U375.1, U376.1, U377.1, U378.1, U379.1, U380.1, U381.1, U382.1, U383.1, U384.1, U385.1, U386.1, U387.1, U388.1, U389.1, U390.1, U391.1, U392.1, U393.1, U394.1, U395.1, U396.1, U397.1, U398.1, U399.1, U400.1, U401.1, U402.1, U403.1, U404.1, U405.1, U406.1, U407.1, U408.1, U409.1, U410.1, U411.1, U412.1, U413.1, U414.1, U415.1, U416.1, U417.1, U418.1, U419.1, U420.8, U421.16, U422.1, U423.24, U424.24, U425.24, U426.24
3I0: U28.9, U36.2
3I1: U28.8, U37.2
3I2: U26.2, U28.7
3I3: U27.2, U28.6
3I4: U16.2, U28.5
3I5: U17.2, U28.4
3I6: U06.2, U28.3
3I7: U07.2, U28.2
3I8: U05.2, U28.23
3I9: U04.2, U28.22
3I10: U15.2, U28.21
3I11: U14.2, U28.20
3I12: U25.2, U28.19
3I13: U24.2, U28.18
3I14: U28.17, U35.2
3I15: U28.16, U34.2
3I16: U122.2, U142.9
3I17: U130.2, U142.8
3I18: U121.2, U142.7
3I19: U129.2, U142.6
3I20: U120.2, U142.5
3I21: U128.2, U142.4
3I22: U119.2, U142.3
3I23: U127.2, U142.2
3I24: U111.2, U142.23
3I25: U100.2, U142.22
3I26: U112.2, U142.21
3I27: U101.2, U142.20
3I28: U113.2, U142.19
3I29: U102.2, U142.18
3I30: U114.2, U142.17
3I31: U103.2, U142.16
3I32: U193.2, U213.9
3I33: U201.2, U213.8
3I34: U192.2, U213.7
3I35: U200.2, U213.6
3I36: U191.2, U213.5
3I37: U199.2, U213.4
3I38: U190.2, U213.3
3I39: U198.2, U213.2
3I40: U182.2, U213.23
3I41: U174.2, U213.22
3I42: U183.2, U213.21
3I43: U175.2, U213.20
3I44: U184.2, U213.19
3I45: U176.2, U213.18
3I46: U185.2, U213.17
3I47: U177.2, U213.16
3I48: U264.2, U284.9
3I49: U272.2, U284.8
3I50: U263.2, U284.7
3I51: U271.2, U284.6
3I52: U262.2, U284.5
3I53: U270.2, U284.4
3I54: U261.2, U284.3
3I55: U269.2, U284.2
3I56: U253.2, U284.23
3I57: U245.2, U284.22
3I58: U254.2, U284.21
3I59: U246.2, U284.20
3I60: U255.2, U284.19
3I61: U247.2, U284.18
3I62: U256.2, U284.17
3I63: U248.2, U284.16
3I64: U335.2, U355.9
3I65: U343.2, U355.8
3I66: U334.2, U355.7
3I67: U342.2, U355.6
3I68: U333.2, U355.5
3I69: U341.2, U355.4
3I70: U332.2, U355.3
3I71: U340.2, U355.2
3I72: U324.2, U355.23
3I73: U316.2, U355.22
3I74: U325.2, U355.21
3I75: U317.2, U355.20
3I76: U326.2, U355.19
3I77: U318.2, U355.18
3I78: U327.2, U355.17
3I79: U319.2, U355.16
3I80: U406.2, U426.9
3I81: U414.2, U426.8
3I82: U405.2, U426.7
3I83: U413.2, U426.6
3I84: U404.2, U426.5
3I85: U412.2, U426.4
3I86: U403.2, U426.3
3I87: U411.2, U426.2
3I88: U395.2, U426.23
3I89: U387.2, U426.22
3I90: U396.2, U426.21
3I91: U388.2, U426.20
3I92: U397.2, U426.19
3I93: U389.2, U426.18
3I94: U398.2, U426.17
3I95: U390.2, U426.16
4I0: U08.9, U76.2
4I1: U08.8, U77.2
4I2: U08.7, U66.2
4I3: U08.6, U67.2
4I4: U08.5, U56.2
4I5: U08.4, U57.2
4I6: U08.3, U46.2
4I7: U08.2, U47.2
4I8: U08.23, U45.2
4I9: U08.22, U44.2
4I10: U08.21, U55.2
4I11: U08.20, U54.2
4I12: U08.19, U65.2
4I13: U08.18, U64.2
4I14: U08.17, U75.2
4I15: U08.16, U74.2
4I16: U126.2, U139.9
4I17: U134.2, U139.8
4I18: U125.2, U139.7
4I19: U133.2, U139.6
4I20: U124.2, U139.5
4I21: U132.2, U139.4
4I22: U123.2, U139.3
4I23: U131.2, U139.2
4I24: U115.2, U139.23
4I25: U107.2, U139.22
4I26: U116.2, U139.21
4I27: U108.2, U139.20
4I28: U117.2, U139.19
4I29: U109.2, U139.18
4I30: U118.2, U139.17
4I31: U110.2, U139.16
4I32: U197.2, U210.9
4I33: U205.2, U210.8
4I34: U196.2, U210.7
4I35: U204.2, U210.6
4I36: U195.2, U210.5
4I37: U203.2, U210.4
4I38: U194.2, U210.3
4I39: U202.2, U210.2
4I40: U186.2, U210.23
4I41: U178.2, U210.22
4I42: U187.2, U210.21
4I43: U179.2, U210.20
4I44: U188.2, U210.19
4I45: U180.2, U210.18
4I46: U189.2, U210.17
4I47: U181.2, U210.16
4I48: U268.2, U281.9
4I49: U276.2, U281.8
4I50: U267.2, U281.7
4I51: U275.2, U281.6
4I52: U266.2, U281.5
4I53: U274.2, U281.4
4I54: U265.2, U281.3
4I55: U273.2, U281.2
4I56: U257.2, U281.23
4I57: U249.2, U281.22
4I58: U258.2, U281.21
4I59: U250.2, U281.20
4I60: U259.2, U281.19
4I61: U251.2, U281.18
4I62: U260.2, U281.17
4I63: U252.2, U281.16
4I64: U339.2, U352.9
4I65: U347.2, U352.8
4I66: U338.2, U352.7
4I67: U346.2, U352.6
4I68: U337.2, U352.5
4I69: U345.2, U352.4
4I70: U336.2, U352.3
4I71: U344.2, U352.2
4I72: U328.2, U352.23
4I73: U320.2, U352.22
4I74: U329.2, U352.21
4I75: U321.2, U352.20
4I76: U330.2, U352.19
4I77: U322.2, U352.18
4I78: U331.2, U352.17
4I79: U323.2, U352.16
4I80: U410.2, U423.9
4I81: U418.2, U423.8
4I82: U409.2, U423.7
4I83: U417.2, U423.6
4I84: U408.2, U423.5
4I85: U416.2, U423.4
4I86: U407.2, U423.3
4I87: U415.2, U423.2
4I88: U399.2, U423.23
4I89: U391.2, U423.22
4I90: U400.2, U423.21
4I91: U392.2, U423.20
4I92: U401.2, U423.19
4I93: U393.2, U423.18
4I94: U402.2, U423.17
4I95: U394.2, U423.16
!CCLR: J1.3, U104.10
!CCLR1: J2.3, U137.10
!CCLR2: J3.3, U208.10
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

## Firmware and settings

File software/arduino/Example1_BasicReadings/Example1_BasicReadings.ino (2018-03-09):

/*
 This basic example shows how to interface with the Magnetic Imaging Tile V3
 with a Chipkit MAX32, with data displayed via the serial port.
 Simple serial commands allow viewing the data in a serial console, or
 sending the data to a program on a host system (such as the accompanying
 Processing example) for display.

 The code primarily uses the internal ADC of the Chipkit MAX32, but
 (slow) code is also provided for using the AD7940 on the tile as
 well.  The speed of the ADC and I/O clocking is essentially the
 limiting factor in framerate, and this should be kept in mind
 when porting to other platforms (e.g. the Arduino Uno).

 The Chipkit MAX32 provides ~128K of RAM, which is enough for a
 short framebuffer (up to about 500 frames) when recording
 high-speed data.

 This code was written in MPIDE 0023-windows-20140316 .
*/

//Define where to pipe serial print statements
//#define terminal Serial //Use with Uno and Chipkit
#define terminal SerialUSB //Use with SAMD21

#define CS_INACTIVE  1
#define CS_ACTIVE    0

//Hardware connections
const byte PIN_ANALOG = A1;

//On Arduino Unos and Red Boards this is the SPI pinout
const byte PIN_CLR = 8;
const byte PIN_CLK = 9;
const byte AD7940_SPI_MISO = 12;
const byte AD7940_SPI_CS = 10;
const byte AD7940_SPI_CLK = 13;

// Frames
#if defined(__AVR_ATmega328P__) || defined(__AVR_ATmega168__)

//We have very limited RAM
#define MAX_BASE_FRAMES  2

#else

//Platforms like SAMD21, ChipKit, and Teensy have far more RAM
//#define MAX_BASE_FRAMES  500
//#define MAX_BASE_FRAMES  250
#define MAX_BASE_FRAMES  100
//#define _8BIT

#endif

#ifdef _8BIT
#define MAX_FRAMES      MAX_BASE_FRAMES*2
uint8_t frames[MAX_FRAMES][64];
#else
#define MAX_FRAMES      MAX_BASE_FRAMES
uint16_t frames[MAX_FRAMES][64];
#endif

// Frame variables
// Magnetic tile reading
int pixelOrder[] = {26, 27, 18, 19, 10, 11, 2, 3, 1, 0, 9, 8, 17, 16, 25, 24};
int subtileOrder[] = {0, 2, 1, 3};
int subtileOffset[] = {0, 4, 32, 36};
uint16_t frame[64];

int numFrames = 0;
int curFrame = 0;

#define MODE_IDLE          0
#define MODE_LIVE          1
#define MODE_HIGHSPEED1    2
#define MODE_HIGHSPEED2    3
#define MODE_HIGHSPEED3    4
#define MODE_HIGHSPEED4    5
#define MODE_PIXEL         6

int curMode = MODE_IDLE;

/*
   Analog Read
*/
int readMagnetometer() {
  //return 0;
  //return analogRead(PIN_ANALOG);
  //return readInternalADC();
  return readAD7940();
  //return read_ad7940();
}

// Take one measurement form the internal ADC
int readInternalADC() {
  int numSamples = 2;
  float sum = 0.0f;
  for (int i = 0; i < numSamples; i++) {
    int sensorValue = analogRead(PIN_ANALOG);
    sum += sensorValue;
  }
  sum /= numSamples;

  //return sensorValue;
  return int(floor(sum));
}


// Take one measurement from an external AD7940 14-bit ADC (SPI)
uint16_t readAD7940() {
  uint16_t value = 0;
  //uint16_t delay_time = 2;

  // Idle
  digitalWrite(AD7940_SPI_CS, HIGH);
  digitalWrite(AD7940_SPI_CLK, HIGH);

  // Enable
  digitalWrite(AD7940_SPI_CS, LOW);

  // Read 16 bits
  for (int i = 0; i < 16; i++) {
    char bit = digitalRead(AD7940_SPI_MISO);
    digitalWrite(AD7940_SPI_CLK, LOW);
    //    delayMicroseconds(delay_time);

    value = value << 1;
    value = value + (bit & 0x01);
    digitalWrite(AD7940_SPI_CLK, HIGH);
    //    delayMicroseconds(delay_time);
  }
  // Disable
  digitalWrite(AD7940_SPI_CS, HIGH);
  //  delayMicroseconds(delay_time);

  return value;
}

/*
   Magnetic Sensors
*/
void clearCounter() {
  digitalWrite(PIN_CLR, 0);
  //delay(10);
  digitalWrite(PIN_CLR, 1);
  //delay(10);
}

void incrementCounter() {
  digitalWrite(PIN_CLK, 1);
  //delay(1);
  digitalWrite(PIN_CLK, 0);
  //delay(1);
}

/*
   Capture one frame from imaging array
*/
void readTileFrame() {

  clearCounter();
  incrementCounter();

  for (int curSubtileIdx = 0; curSubtileIdx < 4; curSubtileIdx++) {
    for (int curIdx = 0; curIdx < 16; curIdx++) {
      // Read value
      int value = readMagnetometer();

      //terminal.println(value);
      //delay(10);

      // Store value in correct frame location
      int frameOffset = pixelOrder[curIdx] + subtileOffset[subtileOrder[curSubtileIdx]];
      //terminal.println(frameOffset);
      //delay(25);
      frame[frameOffset] = value;

      // Increment to next pixel
      incrementCounter();
    }
  }
}

// Display current frame on serial console
void displayCurrentFrame() {
  // Display frame
  //  terminal.println ("\nCurrent Frame");
  int idx = 0;
  for (int i = 0; i < 8; i++) {
    for (int j = 0; j < 8; j++) {
      terminal.print( frame[idx] );
      terminal.print( " " );
      idx += 1;
    }
    terminal.println("");
  }
  terminal.println("*");
}

// Record MAX_FRAMES, as fast as possible
void recordHighSpeedFrames(int frameDelayTime) {
  long startTime = millis();

  for (int curFrame = 0; curFrame < MAX_FRAMES; curFrame++) {
    // Read one frame
    readTileFrame();

    // Store frame
#ifdef _8BIT
    for (int a = 0; a < 64; a++) {
      frames[curFrame][a] = frame[a] >> 2;
    }
#else
    for (int a = 0; a < 64; a++) {
      frames[curFrame][a] = frame[a];
    }
#endif

    if (frameDelayTime > 0) {
      delay(frameDelayTime);
    }
  }

  long endTime = millis();
  terminal.print("Framerate: ");
  terminal.println((float)MAX_FRAMES / ((float)(endTime - startTime) / 1000.0f));
}

// Playback the high speed frames stored
void playbackHighSpeedFrames() {

  for (int curFrame = 0; curFrame < MAX_FRAMES; curFrame++) {
    // Display frame
    //    terminal.print ("\nFrame ");
    //    terminal.println (curFrame);

    int idx = 0;
    for (int i = 0; i < 8; i++) {
      for (int j = 0; j < 8; j++) {
        terminal.print( frames[curFrame][idx] );
        terminal.print( " " );
        idx += 1;
      }
      terminal.println("");
    }
    terminal.println("*");
    delay(50);
  }
}

long startTime = 0;

void setup() {
  // Setup pin modes
  pinMode(PIN_CLR, OUTPUT);
  pinMode(PIN_CLK, OUTPUT);

  // AD7940 ADC Pin modes
  pinMode(AD7940_SPI_CS, OUTPUT);
  pinMode(AD7940_SPI_CLK, OUTPUT);
  pinMode(AD7940_SPI_MISO, INPUT);

  // Setup initial states
  incrementCounter();
  clearCounter();

  // initialize serial:
  terminal.begin(115200);
  while(!terminal); //Wait for user to open this terminal. Useful for SAMD21 and boards that use CDC.

  terminal.println ("Initializing.... Press L (live) or H (high speed), 1, 2, 3, or S (idle)");

  clearCounter();
  incrementCounter();
  delay(100);

  startTime = millis();
}

void loop() {

  //Parse serial data (if any)
  if(terminal.available())
  {
    byte incoming = terminal.read();
    
    if (incoming == 'L') {
      terminal.println("Live");
      curMode = MODE_LIVE;

    } else if (incoming == 'H' || incoming == '1') {
      terminal.println("High-speed Save1");
      curMode = MODE_HIGHSPEED1;

    } else if (incoming == '2') {
      terminal.println("High-speed Save2 (1000hz)");
      curMode = MODE_HIGHSPEED2;

    } else if (incoming == '3') {
      terminal.println("High-speed Save3 (500hz)");
      curMode = MODE_HIGHSPEED3;

    } else if (incoming == '4') {
      terminal.println("High-speed Save4 (250hz)");
      curMode = MODE_HIGHSPEED4;

    } else if (incoming == 'S') {
      terminal.println("Idle");
      curMode = MODE_IDLE;

    } else if (incoming == 'P') {
      terminal.println("Read Pixel 0,0");
      curMode = MODE_PIXEL;
    }
  }

  /*
     Take action based on current mode
  */
  if (curMode == MODE_LIVE) {
    readTileFrame();
    displayCurrentFrame();

  } else if (curMode == MODE_HIGHSPEED1) {
    // Full/maximum speed
    recordHighSpeedFrames(0);
    playbackHighSpeedFrames();
    curMode = MODE_IDLE;

    terminal.println ("Initializing.... Press L (live) or H (high speed), 1, 2, 3, or S (idle)");

  } else if (curMode == MODE_HIGHSPEED2) {
    // ~1000Hz
    recordHighSpeedFrames(1);
    playbackHighSpeedFrames();
    curMode = MODE_IDLE;

    terminal.println ("Initializing.... Press L (live) or H (high speed), 1, 2, 3, or S (idle)");

  } else if (curMode == MODE_HIGHSPEED3) {
    // ~500Hz
    recordHighSpeedFrames(2);
    playbackHighSpeedFrames();
    curMode = MODE_IDLE;

    terminal.println ("Initializing.... Press L (live) or H (high speed), 1, 2, 3, or S (idle)");

  } else if (curMode == MODE_HIGHSPEED4) {
    // ~250Hz
    recordHighSpeedFrames(4);
    playbackHighSpeedFrames();
    curMode = MODE_IDLE;

    terminal.println ("Initializing.... Press L (live) or H (high speed), 1, 2, 3, or S (idle)");

  } else if (curMode == MODE_PIXEL) {
    //Read single pixel. Good for testing.
    
    curMode = MODE_IDLE;

    terminal.println ("Initializing.... Press L (live) or H (high speed), 1, 2, 3, or S (idle)");
  }

  //delay(10);
}

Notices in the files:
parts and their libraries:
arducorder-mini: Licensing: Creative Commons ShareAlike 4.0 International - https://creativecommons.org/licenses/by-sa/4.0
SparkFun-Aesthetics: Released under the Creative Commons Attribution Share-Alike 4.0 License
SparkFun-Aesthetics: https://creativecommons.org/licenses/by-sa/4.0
